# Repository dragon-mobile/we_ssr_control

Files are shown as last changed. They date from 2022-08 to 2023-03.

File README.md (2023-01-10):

# we_ssr_control

<br/>



<br/>

The WEMOS Solid State Relay Controller is primarily meant to be
used with an open hardware solid state relay PCBs that is being co-developed
alongside this project as part of my Dragon Mobile GitHub organization to make
useful hardware with associated firmware and software for the tiny home, van
life and maker communities.

## Visual 3D examples

Top view<br/>
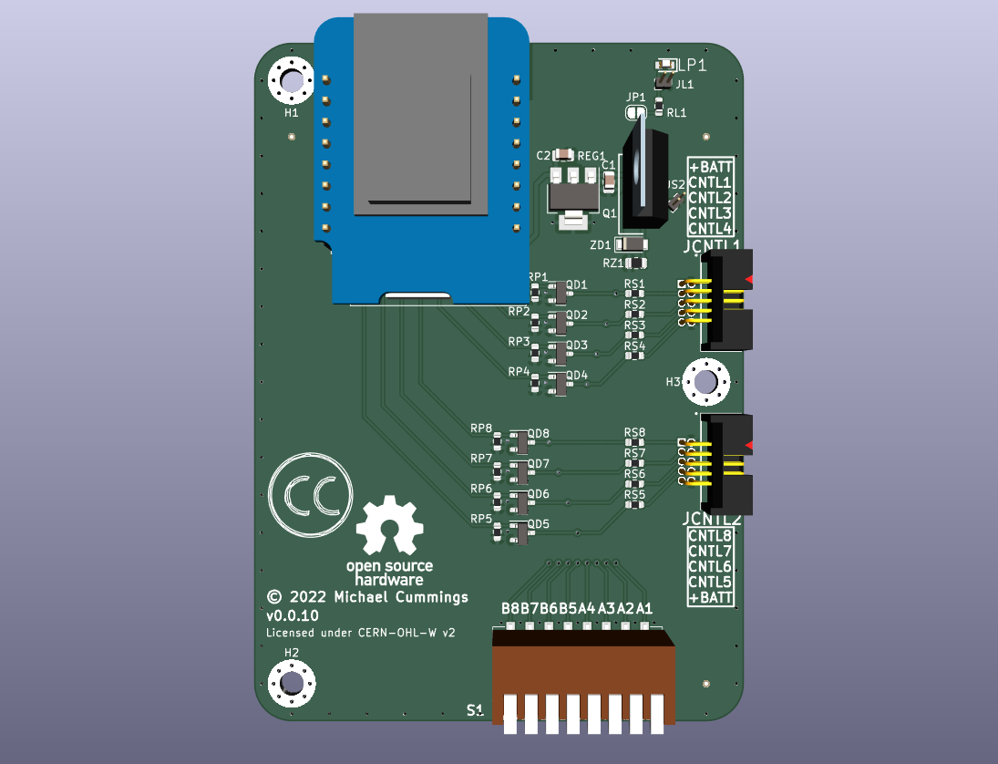
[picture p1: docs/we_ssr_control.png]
Top view 3D rendering of the circuit board in FreeCAD Circuit board top view
<br/>
Bottom view<br/>
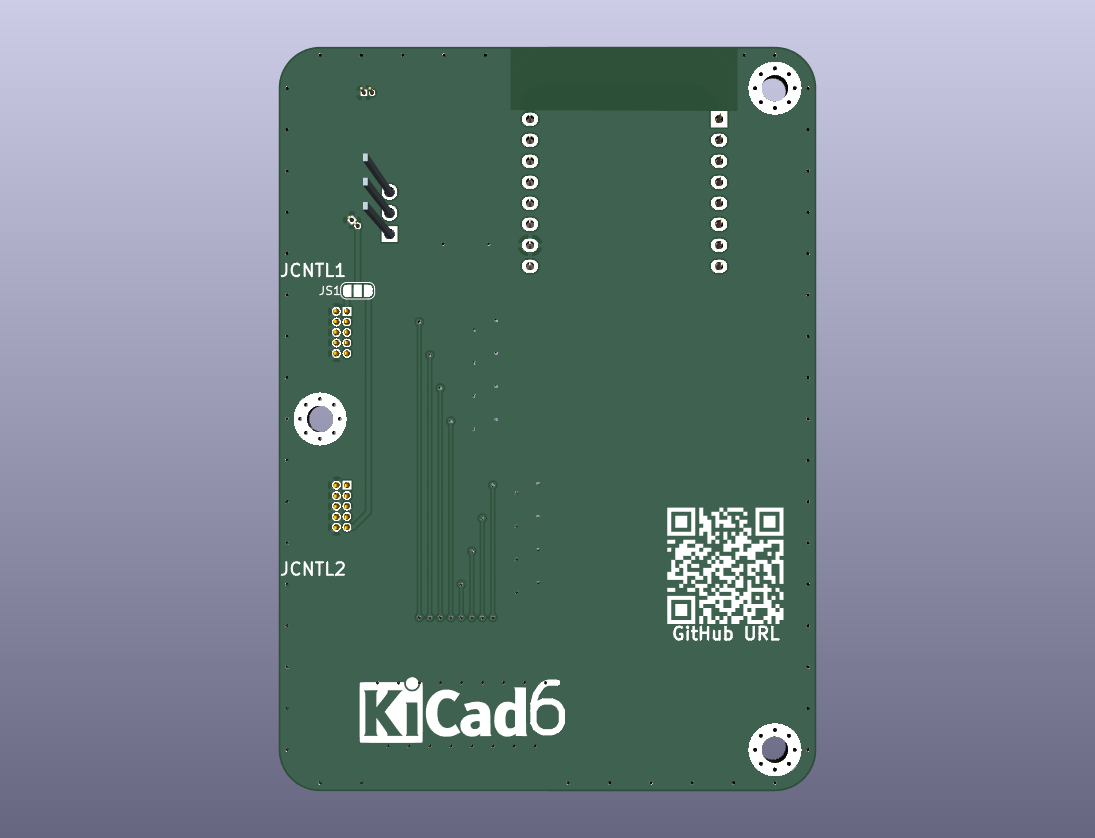
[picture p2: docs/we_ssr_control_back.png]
Bottom view 3D rendering of the circuit board in FreeCAD Circuit board bottom view
<br/>

## Contributing

Contributors are welcome.
Please note that this project has a [Contributor Covenant Code of Conduct].
By participating in this project you agree to abide by its terms.

All intentionally contributed hardware will be considered to be contributed
under the [CERN] license without any additional terms or conditions.

All intentionally contributed code will be considered to be contributed
under a [MIT] license without any additional terms or conditions.
Please include your information in a comment on all code files for the copyright
etc.

All intentionally contributed documentation, CAD files and libraries, footprints,
artwork or non-code text like this README etc. will be considered to be
contributed under the same [CC-BY-SA] license without any additional terms or
conditions.

Pull requests are always welcome. For major changes, please open an issue first
to discuss what you would like to change.
Please make sure to update or add tests as appropriate for all software changes.

## Licenses

GitHub<br/>

All hardware is licensed under the

  * [CERN] - CERN-OHL-W-2.0
  
You can find a copy of the CERN Open Hardware License - Weakly-reciprocal v2.0
in the [LICENSE-CERN-OHL-W-2] file and the how-to guide in the
[CERN-HOWTO_GUIDE] file.

All code is licensed under the

  * [MIT] - MIT License

You can find a copy of the license in the [LICENSE-MIT] file.

All documentation like this README is licensed under the Creative Commons
Attribution-ShareAlike 4.0 International License (CC-BY-SA).

All original CAD files and libraries, footprints, and artwork are also licensed
under the
Creative Commons Attribution-ShareAlike 4.0 International License (CC-BY-SA).
You can find a copy of the [CC-BY-SA] license in the [LICENSE-CC-BY-SA] file.

If after reading the above license files, how-tos, and related FAQs on the
linked license sites on how they apply to the project please either open an
issue or contact me (Michael Cummings) via my Github email and I will try
to guided you through my understanding of how it works.

[CC-BY-SA]: http://creativecommons.org/licenses/by-sa/4.0/
[CERN]: https://ohwr.org/project/cernohl/wikis/Documents/CERN-OHL-version-2
[CERN-HOWTO_GUIDE]: docs/cern_ohl_w_v2_howto.pdf
[Contributor Covenant Code of Conduct]: CODE_OF_CONDUCT.md 
[LICENSE-CC-BY-SA]: LICENSE-CC-BY-SA
[LICENSE-CERN-OHL-W-2]: CERN-OHL-W-2
[LICENSE-MIT]: LICENSE-MIT
[MIT]: https://opensource.org/licenses/MIT

<hr>
Copyright &copy; 2022-2023, Michael Cummings<br/>
<a rel="license" href="http://creativecommons.org/licenses/by-sa/4.0/">

</a>

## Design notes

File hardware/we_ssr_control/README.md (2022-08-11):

# we_ssr_control
WeMos D Mini control board for Solid State Relay boards

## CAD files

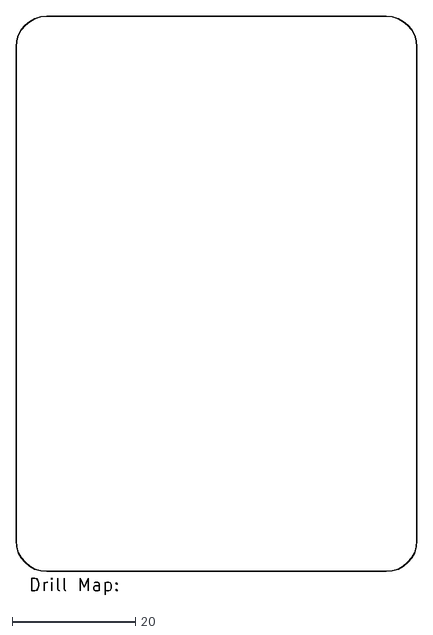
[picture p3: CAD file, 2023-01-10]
production/we_ssr_control-NPTH-drl_map.dxf
65.0 x 93.8

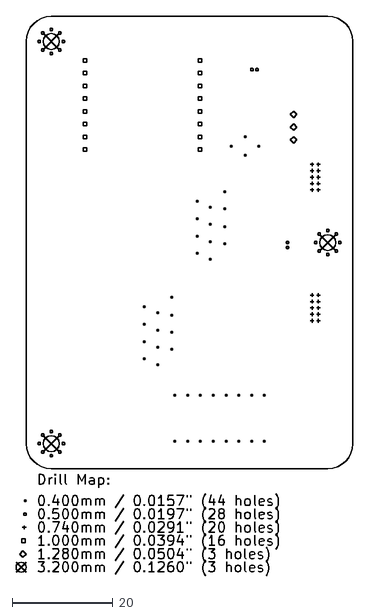
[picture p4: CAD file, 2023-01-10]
production/we_ssr_control-PTH-drl_map.dxf
67.0 x 111.3

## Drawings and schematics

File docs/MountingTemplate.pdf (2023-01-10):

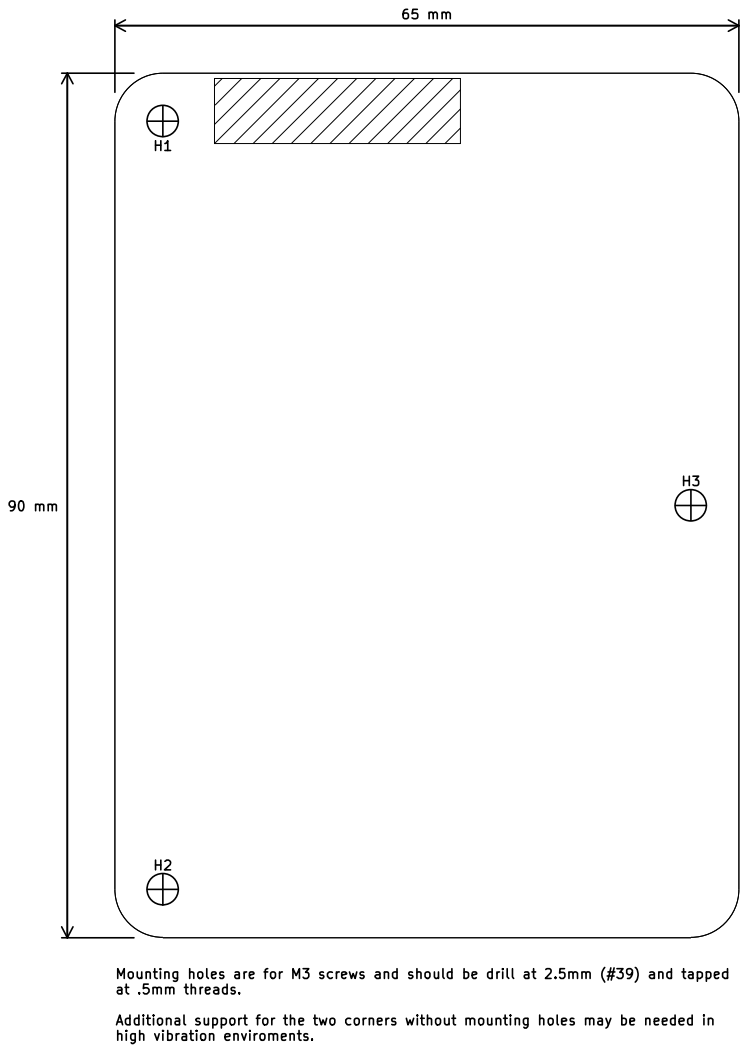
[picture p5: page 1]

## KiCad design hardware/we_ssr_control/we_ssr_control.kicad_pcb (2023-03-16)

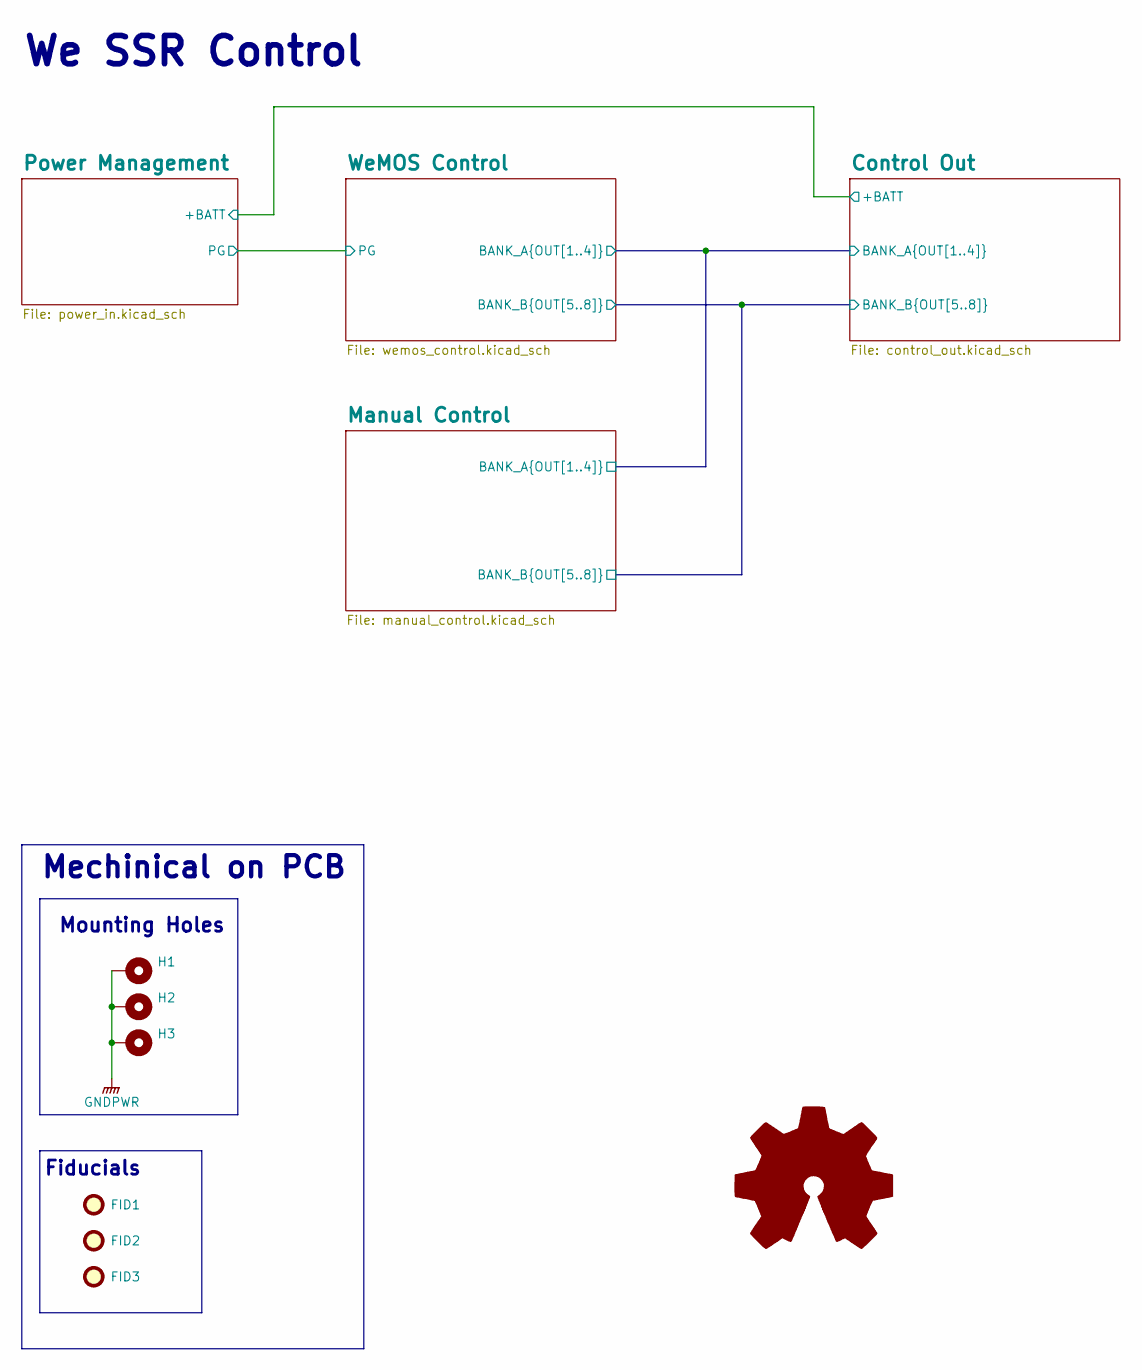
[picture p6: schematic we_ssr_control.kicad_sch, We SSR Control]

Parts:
FID1, FID2, FID3: Fiducial; Fiducial_0.5mm_Mask1mm
H1, H2, H3: MountingHole_Pad; MountingHole_3.2mm_M3_Pad_Via

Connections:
GNDPWR: H1.1, H2.1, H3.1; also elsewhere on the board

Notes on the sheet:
Fiducials
We SSR Control
Mechinical on PCB
Mounting Holes

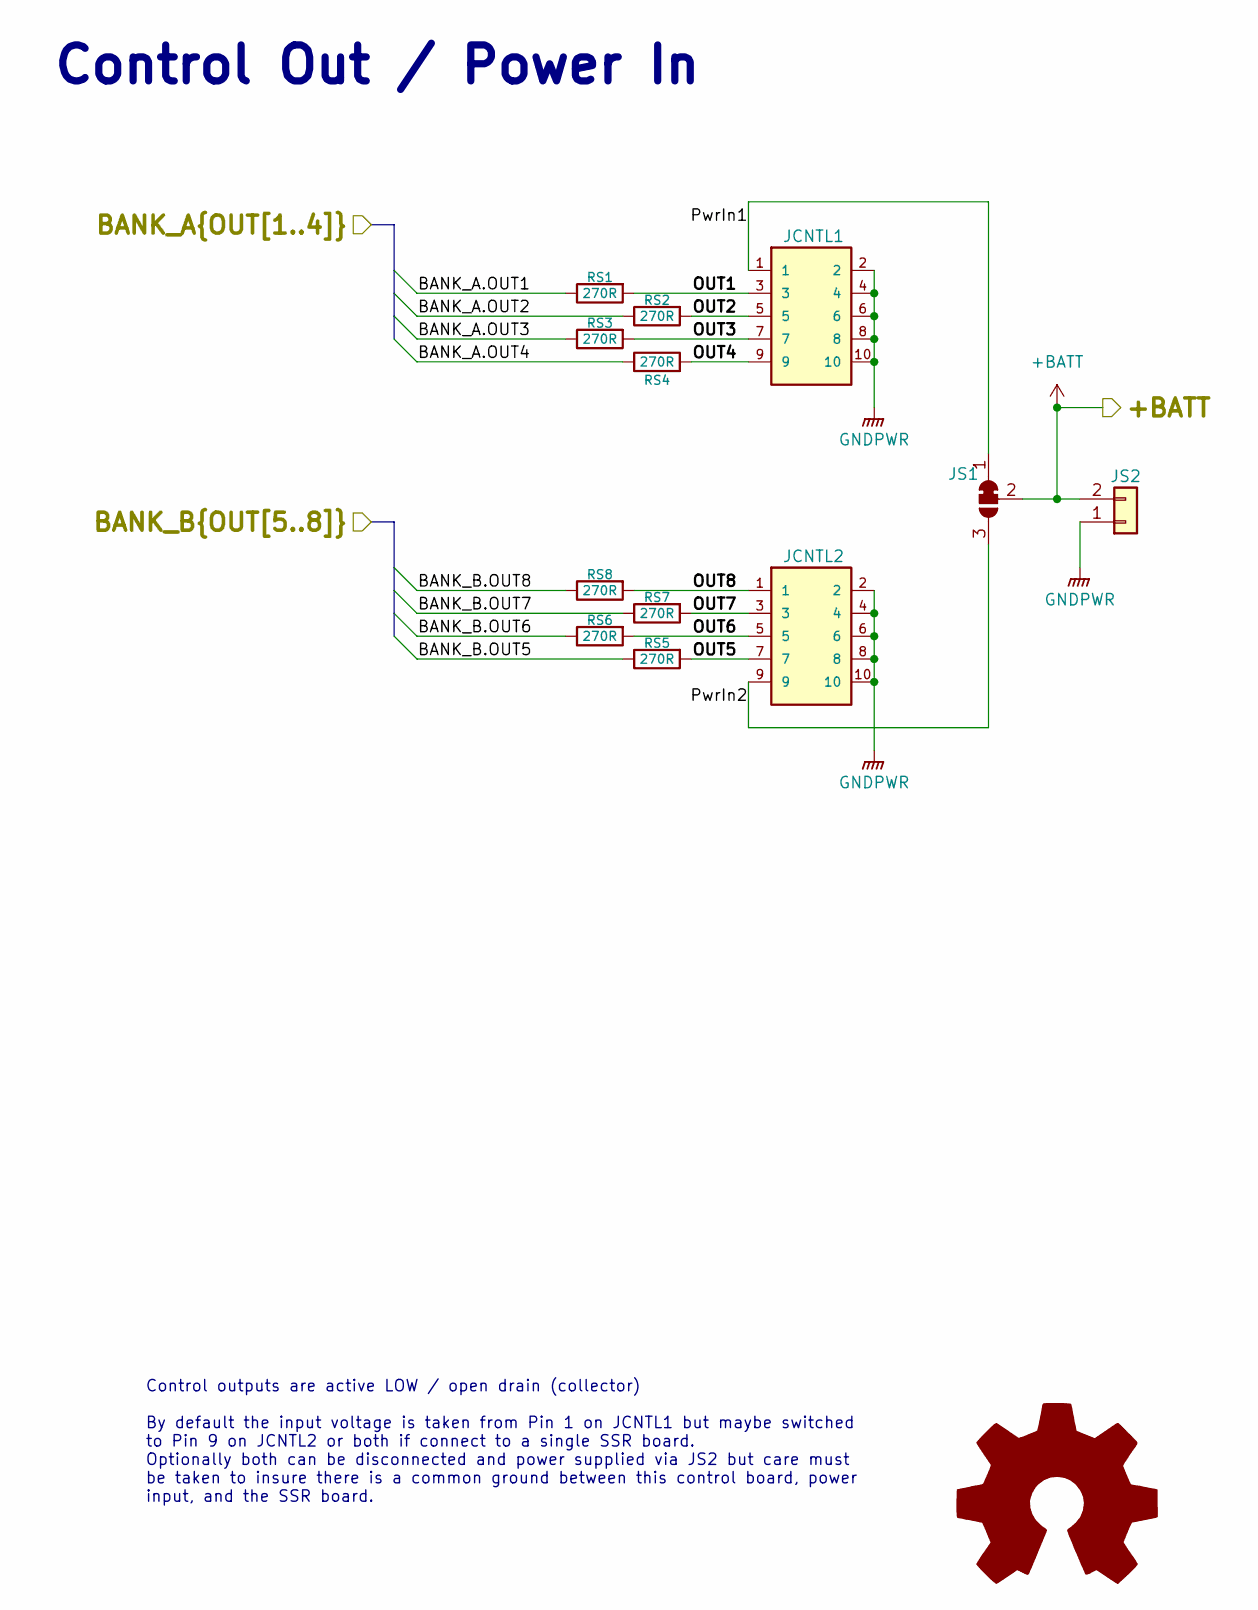
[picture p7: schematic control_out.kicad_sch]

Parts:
JCNTL1, JCNTL2: SHF-105-01-L-D-RA; SAMTEC_SHF-105-01-L-D-RA; Mouser Part Number 200-SHF10501LDRATR
JS1: SolderJumper_3_Bridged12; SolderJumper-3_P1.3mm_Bridged12_RoundedPad1.0x1.5mm_NumberL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
JS2: Conn_01x02; PinHeader_1x02_P1.00mm_Vertical
RS1, RS2, RS3, RS4, RS5, RS6, RS7, RS8: 270R; R_0603_1608Metric; Mouser Part Number 755-SDR03EZPJ271

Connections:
+BATT: JS1.2 (C), JS2.2; also elsewhere on the board
/Control Out/BANK_A.OUT1: RS1.1; also elsewhere on the board
/Control Out/BANK_A.OUT2: RS2.1; also elsewhere on the board
/Control Out/BANK_A.OUT3: RS3.1; also elsewhere on the board
/Control Out/BANK_A.OUT4: RS4.1; also elsewhere on the board
/Control Out/BANK_B.OUT5: RS5.1; also elsewhere on the board
/Control Out/BANK_B.OUT6: RS6.1; also elsewhere on the board
/Control Out/BANK_B.OUT7: RS7.1; also elsewhere on the board
/Control Out/BANK_B.OUT8: RS8.1; also elsewhere on the board
/Control Out/OUT1: JCNTL1.3, RS1.2
/Control Out/OUT2: JCNTL1.5, RS2.2
/Control Out/OUT3: JCNTL1.7, RS3.2
/Control Out/OUT4: JCNTL1.9, RS4.2
/Control Out/OUT5: JCNTL2.7, RS5.2
/Control Out/OUT6: JCNTL2.5, RS6.2
/Control Out/OUT7: JCNTL2.3, RS7.2
/Control Out/OUT8: JCNTL2.1, RS8.2
/Control Out/PwrIn1: JCNTL1.1, JS1.1 (A)
/Control Out/PwrIn2: JCNTL2.9, JS1.3 (B)
GNDPWR: JCNTL1.2, JCNTL1.4, JCNTL1.6, JCNTL1.8, JCNTL1.10, JCNTL2.2, JCNTL2.4, JCNTL2.6, JCNTL2.8, JCNTL2.10, JS2.1; also elsewhere on the board

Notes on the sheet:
Control Out / Power In
Control outputs are active LOW / open drain (collector) By default the input voltage is taken from Pin 1 on JCNTL1 but maybe switched to Pin 9 on JCNTL2 or both if connect to a single SSR board. Optionally both can be disconnected and power supplied via JS2 but care must be taken to insure there is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

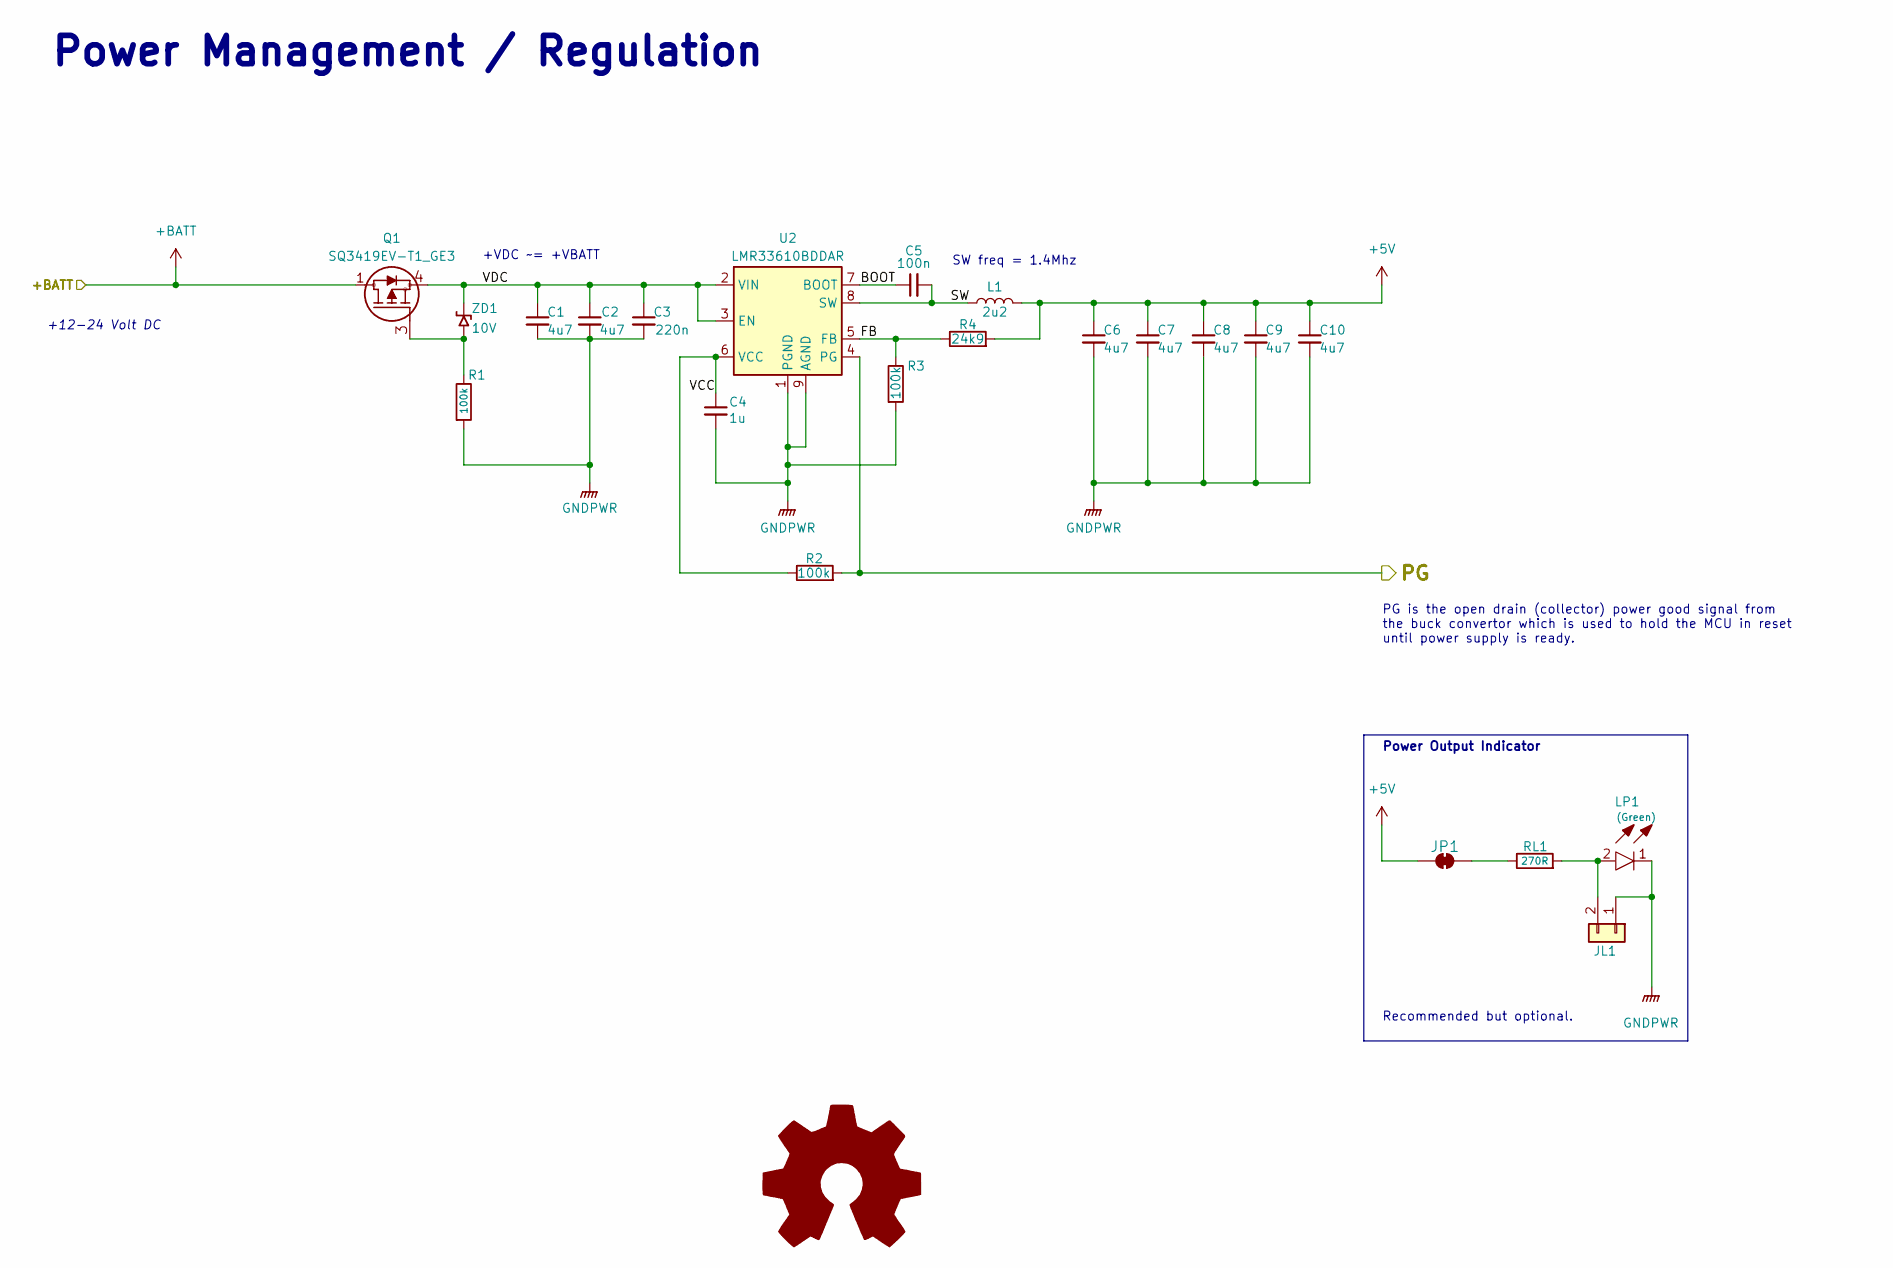
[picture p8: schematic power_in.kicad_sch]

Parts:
C1, C2, C6, C7, C8, C9, C10: 4u7; C_0805_2012Metric; Mouser Part Number 810-CGA4J1X7R1H475K1
C3: 220n; C_0603_1608Metric; Mouser Part Number 810-CGA3E3X7R1H224K
C4: 1u; C_0603_1608Metric; Mouser Part Number 810-CGA3E3X5R1H105K
C5: 100n; C_0603_1608Metric; Mouser Part Number 810-CGA3E2X7R1H104K
JL1: Conn_01x02; PinHeader_1x02_P1.00mm_Vertical
JP1: SolderJumper_2_Bridged; SolderJumper-2_P1.3mm_Bridged_RoundedPad1.0x1.5mm
L1: 2u2; L_1008_2520Metric; Mouser Part Number 810-TFM252012ALVA2R2
LP1: LTST-C190KGKT; LEDC1608X80N; Mouser Part Number 859-LTST-C190KGKT
Q1: SQ3419EV-T1_GE3; SOT95P284X110-6N; Mouser Part Number 78-SQ3419EV-T1_GE3
R1, R2, R3: 100k; R_0603_1608Metric; Mouser Part Number 667-ERJ-PA3F1003V
R4: 24k9; R_0603_1608Metric; Mouser Part Number 667-ERJ-PA3F2492V
RL1: 270R; R_0603_1608Metric; Mouser Part Number 755-SDR03EZPJ271
U2: LMR33610BDDAR; Texas_HSOP-8-1EP_3.9x4.9mm_P1.27mm_ThermalVias; Mouser Part Number 595-LMR33610BDDAR
ZD1: 10V; D_0805_2012Metric; Mouser Part Number 821-BZY55B10RBG

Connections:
+5V: C6.1, C7.1, C8.1, C9.1, C10.1, JP1.1 (A), L1.2, R4.2; also elsewhere on the board
+BATT: Q1.1 (D), Q1.2 (D), Q1.5 (D), Q1.6 (D); also elsewhere on the board
/Power Management/BOOT: C5.1, U2.7 (BOOT)
/Power Management/FB: R3.1, R4.1, U2.5 (FB)
/Power Management/PG: R2.2, U2.4 (PG); also elsewhere on the board
/Power Management/SW: C5.2, L1.1, U2.8 (SW)
/Power Management/VCC: C4.1, R2.1, U2.6 (VCC)
/Power Management/VDC: C1.1, C2.1, C3.1, Q1.4 (S), U2.2 (VIN), U2.3 (EN), ZD1.1
GNDPWR: C1.2, C2.2, C3.2, C4.2, C6.2, C7.2, C8.2, C9.2, C10.2, JL1.1, LP1.1, R1.2, R3.2, U2.1 (PGND), U2.9 (AGND); also elsewhere on the board
unnamed: JL1.2, LP1.2, RL1.2
unnamed: JP1.2 (B), RL1.1
unnamed: Q1.3 (G), R1.1, ZD1.2

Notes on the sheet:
+12-24 Volt DC
PG is the open drain (collector) power good signal from the buck convertor which is used to hold the MCU in reset until power supply is ready.
Recommended but optional.
SW freq = 1.4Mhz
Power Management / Regulation
Power Output Indicator
+VDC ~= +VBATT

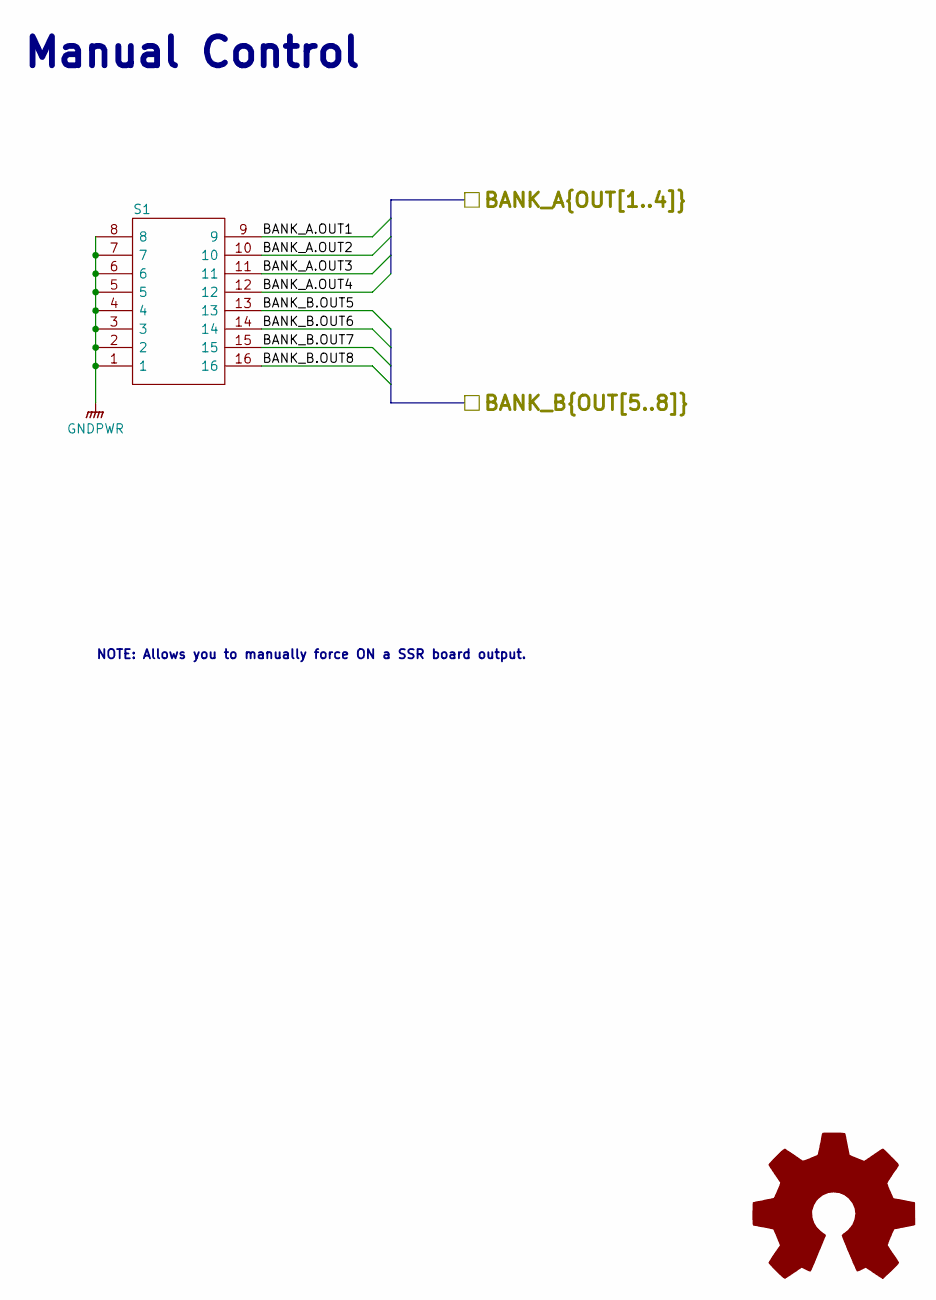
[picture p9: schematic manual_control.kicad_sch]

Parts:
S1: 193-8MS; 1938MS; Mouser Part Number 774-1938MS

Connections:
/Control Out/BANK_A.OUT1: S1.9; also elsewhere on the board
/Control Out/BANK_A.OUT2: S1.10; also elsewhere on the board
/Control Out/BANK_A.OUT3: S1.11; also elsewhere on the board
/Control Out/BANK_A.OUT4: S1.12; also elsewhere on the board
/Control Out/BANK_B.OUT5: S1.13; also elsewhere on the board
/Control Out/BANK_B.OUT6: S1.14; also elsewhere on the board
/Control Out/BANK_B.OUT7: S1.15; also elsewhere on the board
/Control Out/BANK_B.OUT8: S1.16; also elsewhere on the board
GNDPWR: S1.1, S1.2, S1.3, S1.4, S1.5, S1.6, S1.7, S1.8; also elsewhere on the board

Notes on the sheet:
Manual Control
NOTE: Allows you to manually force ON a SSR board output.

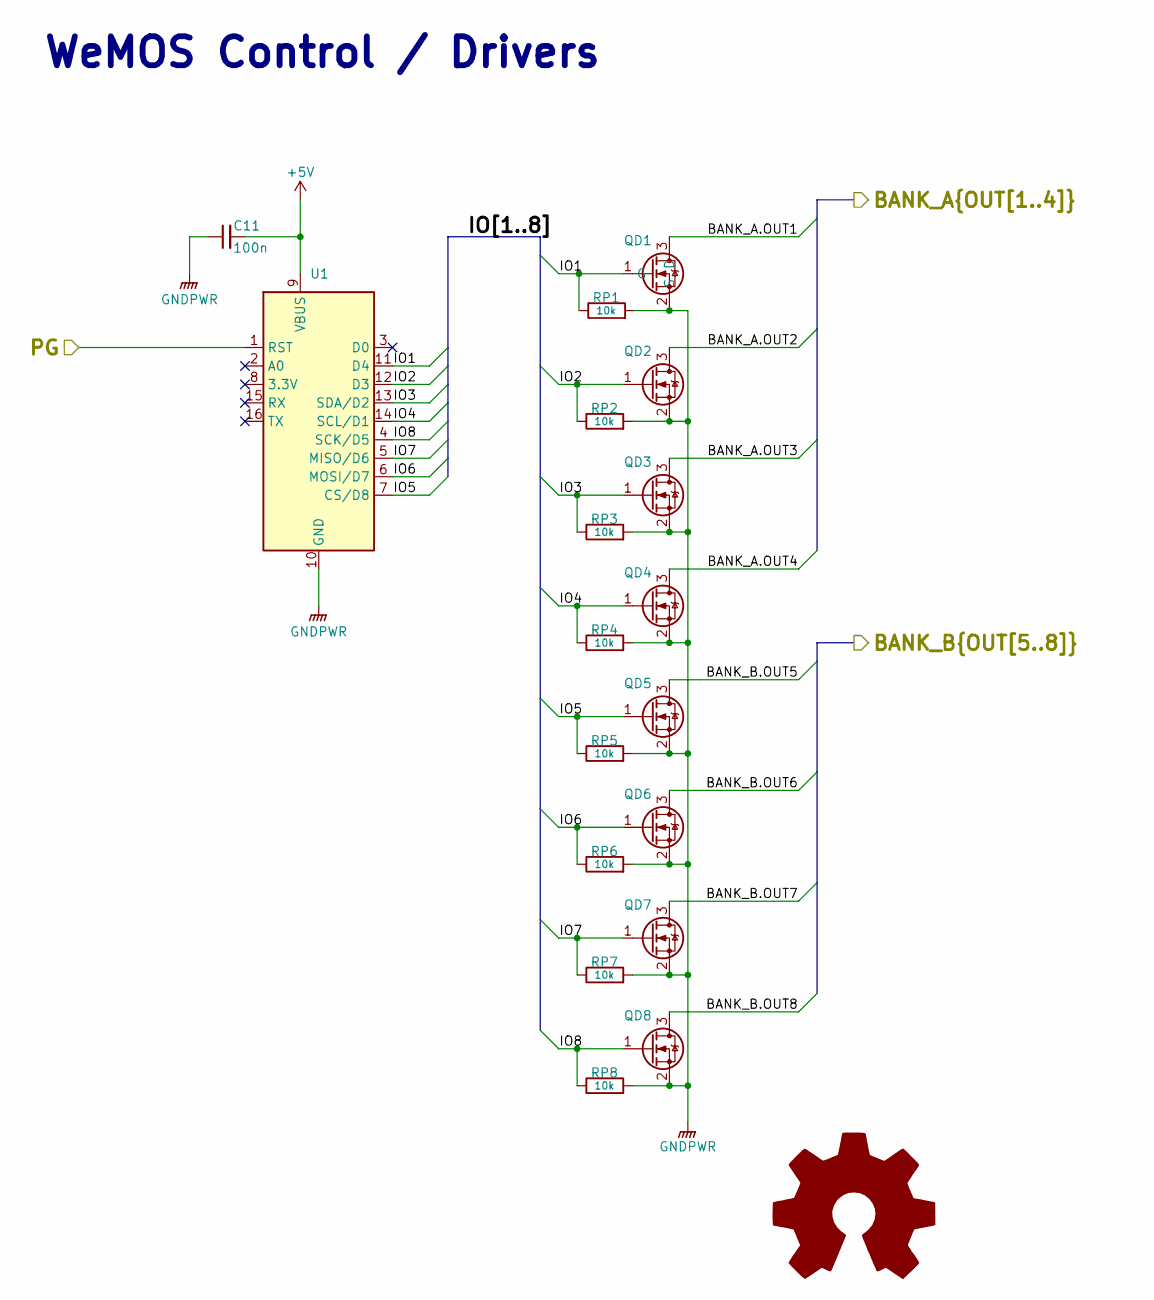
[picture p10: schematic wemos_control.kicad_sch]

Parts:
C11: 100n; C_0603_1608Metric; Mouser Part Number 810-CGA3E2X7R1H104K
QD1, QD2, QD3, QD4, QD5, QD6, QD7, QD8: 2N7002K; 2V7002KT1G; Mouser Part Number 863-2V7002KT1G
RP1, RP2, RP3, RP4, RP5, RP6, RP7, RP8: 10k; R_0603_1608Metric; Mouser Part Number 755-SDR03EZPJ103
U1: WeMos_D1_mini; WEMOS_D1_mini_light

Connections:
+5V: C11.2, U1.9 (VBUS); also elsewhere on the board
/Control Out/BANK_A.OUT1: QD1.3 (D); also elsewhere on the board
/Control Out/BANK_A.OUT2: QD2.3 (D); also elsewhere on the board
/Control Out/BANK_A.OUT3: QD3.3 (D); also elsewhere on the board
/Control Out/BANK_A.OUT4: QD4.3 (D); also elsewhere on the board
/Control Out/BANK_B.OUT5: QD5.3 (D); also elsewhere on the board
/Control Out/BANK_B.OUT6: QD6.3 (D); also elsewhere on the board
/Control Out/BANK_B.OUT7: QD7.3 (D); also elsewhere on the board
/Control Out/BANK_B.OUT8: QD8.3 (D); also elsewhere on the board
/Power Management/PG: U1.1 (RST); also elsewhere on the board
/WeMOS Control/IO1: QD1.1 (G), RP1.1, U1.11 (D4)
/WeMOS Control/IO2: QD2.1 (G), RP2.1, U1.12 (D3)
/WeMOS Control/IO3: QD3.1 (G), RP3.1, U1.13 (SDA/D2)
/WeMOS Control/IO4: QD4.1 (G), RP4.1, U1.14 (SCL/D1)
/WeMOS Control/IO5: QD5.1 (G), RP5.1, U1.7 (CS/D8)
/WeMOS Control/IO6: QD6.1 (G), RP6.1, U1.6 (MOSI/D7)
/WeMOS Control/IO7: QD7.1 (G), RP7.1, U1.5 (MISO/D6)
/WeMOS Control/IO8: QD8.1 (G), RP8.1, U1.4 (SCK/D5)
GNDPWR: C11.1, QD1.2 (S), QD2.2 (S), QD3.2 (S), QD4.2 (S), QD5.2 (S), QD6.2 (S), QD7.2 (S), QD8.2 (S), RP1.2, RP2.2, RP3.2, RP4.2, RP5.2, RP6.2, RP7.2, RP8.2, U1.10 (GND); also elsewhere on the board

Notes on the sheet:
WeMOS Control / Drivers

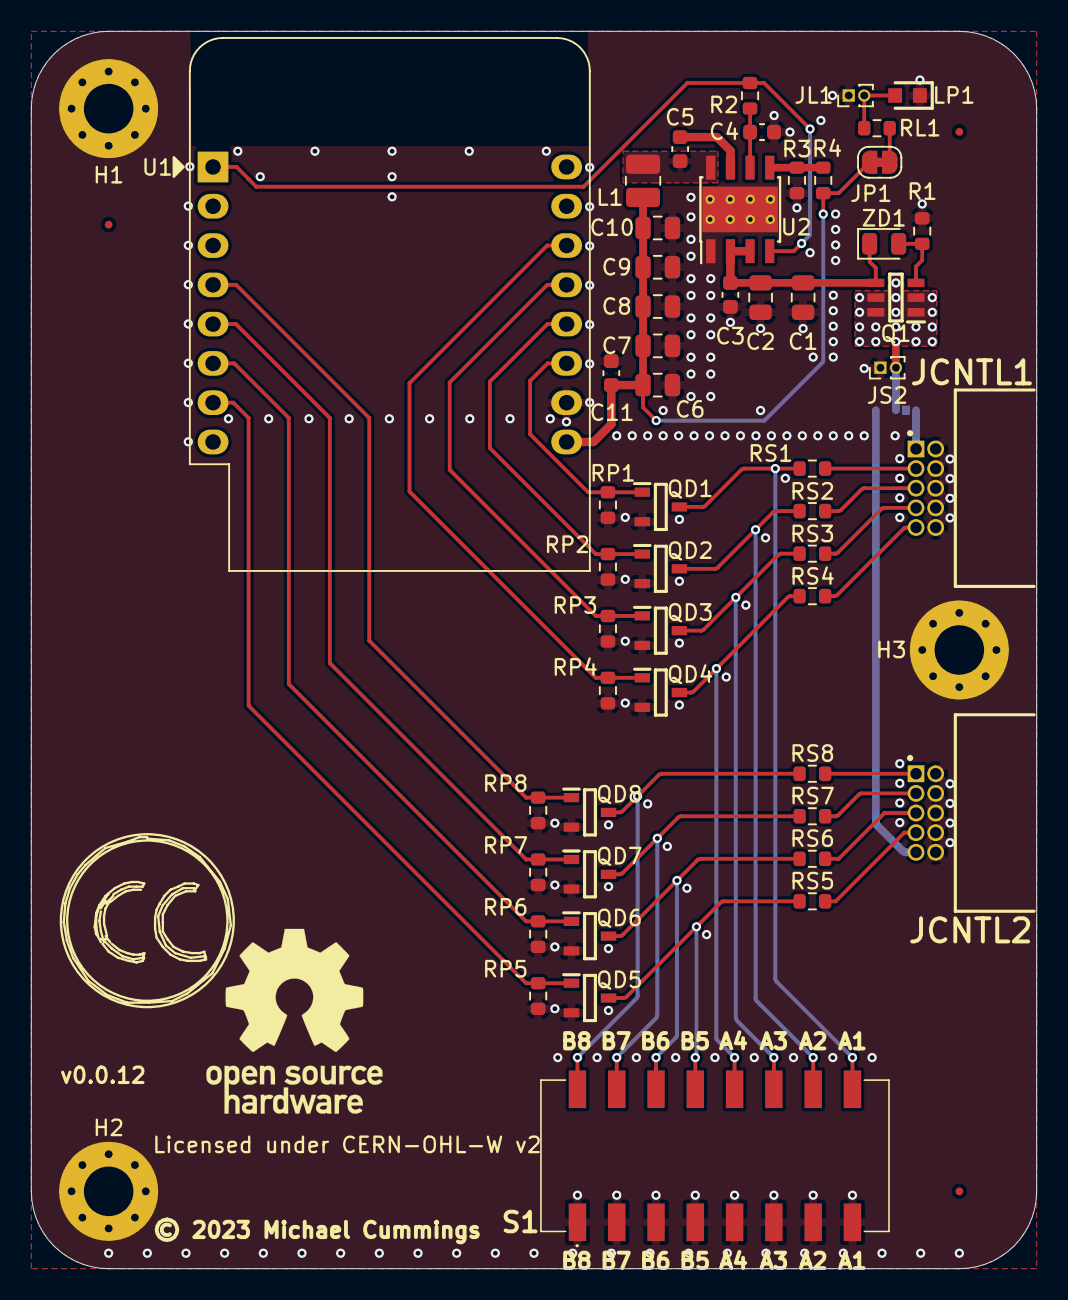
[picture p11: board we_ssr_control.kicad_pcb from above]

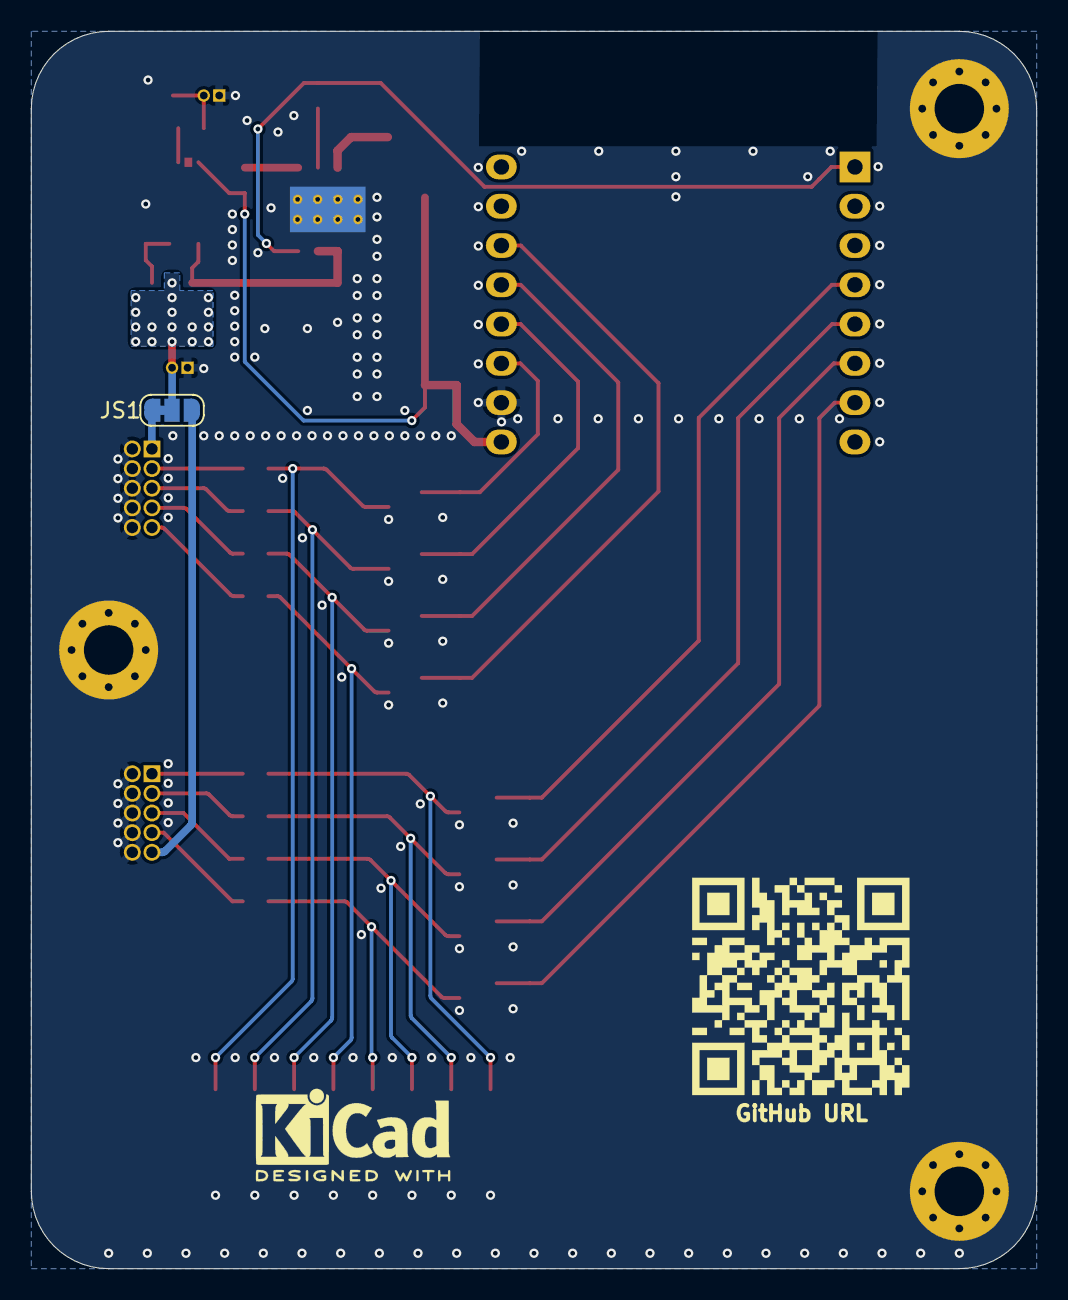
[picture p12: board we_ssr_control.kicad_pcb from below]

Board: 2 copper layers, 65.0 x 80.0 mm, 63 parts (3 on the bottom side), 38 nets.

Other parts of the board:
JCNTL1_Label: JCNTL1_Label
JCNTL2_Label: JCNTL2_Label
QRCode1: GitHub URL; LOGO
REF_KiCAD: KiCad-Logo2_5mm_SilkScreen

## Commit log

2022-08-11 Major re-orginization of project
    [193-8MS.STEP, we_ssr_control.kicad_pcb, we_ssr_control.kicad_sch]
2022-12-09 WIP control connector changes
    [we_ssr_control.kicad_pcb, we_ssr_control.kicad_sch]
2023-01-04 WIP for updated layout
    [we_ssr_control.kicad_pcb, we_ssr_control.kicad_sch]
2023-01-10 Add PCB images to docs/
2023-01-10 Add first draft production files
    [we_ssr_control-B_Cu.gbr, we_ssr_control-B_Mask.gbr, we_ssr_control-B_Paste.gbr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]
2023-01-10 Updated README and added MountingTemplate in docs/
2023-01-10 Minor updates for v0.0.9
    [we_ssr_control.kicad_pcb, we_ssr_control.kicad_sch]
2023-01-29 Changed schematic to hierarchical style with mutliple sheets
    [we_ssr_control.kicad_pcb, we_ssr_control.kicad_sch]
2023-01-29 Updated metadata to v0.0.10
    [we_ssr_control.kicad_pcb]
2023-01-29 Misc updates to Scheme files.
    [control_out.kicad_sch, manual_control.kicad_sch, power_in.kicad_sch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]
2023-01-29 Cleanup PCB traces.
    [we_ssr_control.kicad_pcb]
2023-02-03 Corrected footprint of RZ1 from 0805 to 0603
    [power_in.kicad_sch]
2023-02-03 Cleanup of old footprints,3dmodels, and symbols
    [193-8MS.STEP]
2023-02-03 Merged all symbol, 3dmodel, and footprint changes
    [power_in.kicad_sch, we_ssr_control.kicad_pcb, we_ssr_control.kicad_sch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]
2023-02-03 Updated metadata
    [control_out.kicad_sch, manual_control.kicad_sch, power_in.kicad_sch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]
2023-02-08 Power supply changes plus misc.
    [control_out.kicad_sch, manual_control.kicad_sch, power_in.kicad_sch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]
2023-02-13 Pre KiCad 7.0.0 WIP
    [control_out.kicad_sch, manual_control.kicad_sch, we_ssr_control.kicad_pcb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]
2023-02-13 Updated to KiCAD 7 and some footprint updates
    [control_out.kicad_sch, manual_control.kicad_sch, power_in.kicad_sch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]
2023-03-16 Commit before removing git submodules
    [manual_control.kicad_sch, we_ssr_control.kicad_pcb, wemos_control.kicad_sch]

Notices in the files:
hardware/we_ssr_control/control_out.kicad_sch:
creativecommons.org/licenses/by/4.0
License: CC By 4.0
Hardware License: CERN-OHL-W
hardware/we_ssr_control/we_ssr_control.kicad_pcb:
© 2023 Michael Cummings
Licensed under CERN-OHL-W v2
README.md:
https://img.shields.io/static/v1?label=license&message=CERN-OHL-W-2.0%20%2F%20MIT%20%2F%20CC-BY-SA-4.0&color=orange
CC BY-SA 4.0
